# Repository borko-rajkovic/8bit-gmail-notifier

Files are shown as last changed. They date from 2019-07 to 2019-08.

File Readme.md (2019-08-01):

[][linkedin-url]

<!-- PROJECT LOGO -->
<br />
<p align="center">
  <a href="https://github.com/borko-rajkovic/8bit-gmail-notifier">
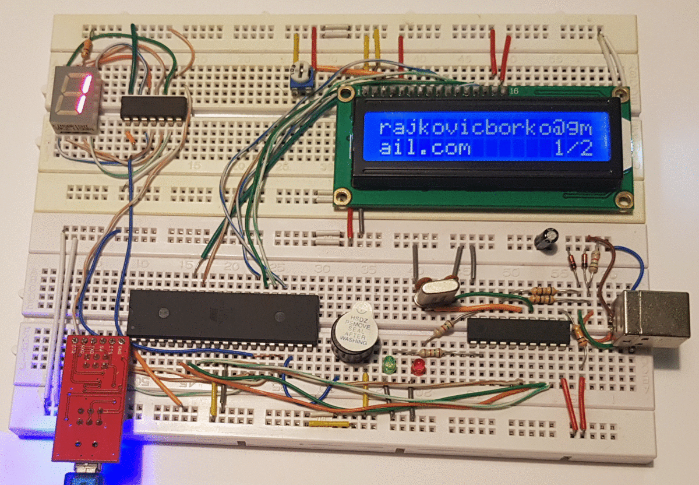
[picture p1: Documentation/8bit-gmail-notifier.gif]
    
  </a>

  <h3 align="center">8bit Gmail Notifier</h3>

  <p align="center">
    Breadboard Gmail notifier written in Assembly
    <br />
    <a href="https://github.com/borko-rajkovic/8bit-gmail-notifier/issues">Report Bug</a>
    ·
    <a href="https://github.com/borko-rajkovic/8bit-gmail-notifier/issues">Request Feature</a>
  </p>
</p>

<!-- TABLE OF CONTENTS -->

## Table of Contents

- [Demo](#demo)
- [Features](#features)
- [About the Project](#about-the-project)
  - [Built With](#built-with)
  - [Schematics](#schematics)
    - [Complete breadboard](#complete-breadboard)
    - [USBtinyISP Programmer](#usbtinyisp-programmer)
    - [BOM (Bill of materials)](#bom-bill-of-materials)
- [Getting Started](#getting-started)
  - [Pre-requisites](#pre-requisites)
  - [Set up project](#set-up-project)
  - [Connect to AVR](#connect-to-avr)
  - [Reading AVR memory and fuses](#reading-avr-memory-and-fuses)
  - [Writing fuses](#writing-fuses)
  - [Writing flash and EEPROM memory](#writing-flash-and-eeprom-memory)
- [Contributing](#contributing)
- [Contact](#contact)

<!-- DEMO -->

## Demo

Watch device in live action [here](https://youtu.be/EqjDfDrvmFI)

## Features

- Buzzer play melody on new mail
- 7-segment display of unread email count (animated)
- LCD display newest email sender and subject
- EEPROM data storage in case of power loss

<!-- ABOUT THE PROJECT -->

## About The Project

You always wanted to learn microcontroller programming in Assembly building something useful?

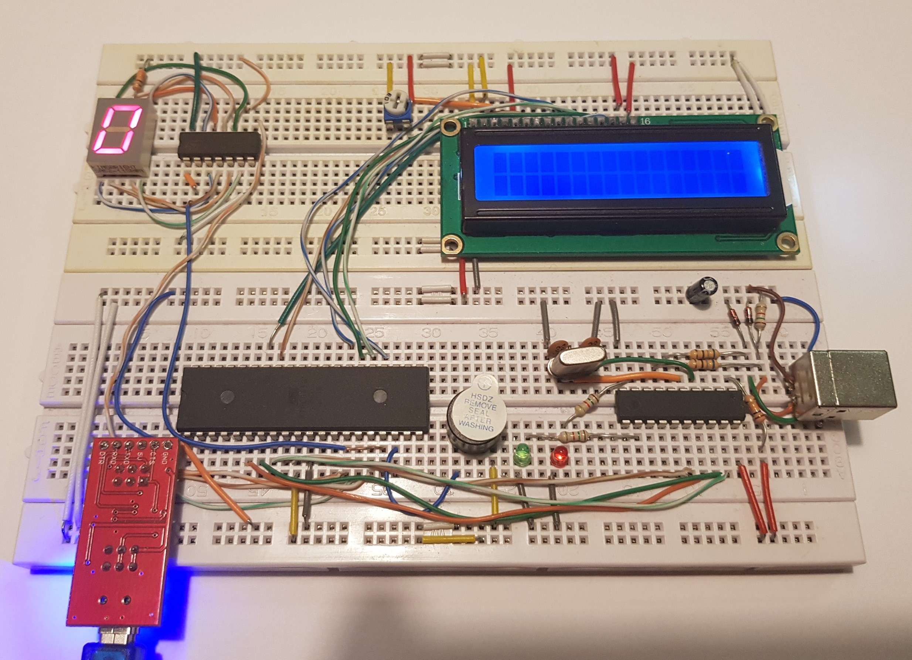
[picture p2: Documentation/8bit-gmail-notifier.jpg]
a


With this project you can learn the basic concepts of AVR MCU programming in Assembly, such as

- Using shift-register for 7-segment display
- Animating digit using Timer/Counter
- Writing to LCD display
- Making tones and melodies with PWM
- Read/Write to EEPROM
- Connecting to PC with UART

### Built With

Assembly - Atmel Studio 7.0

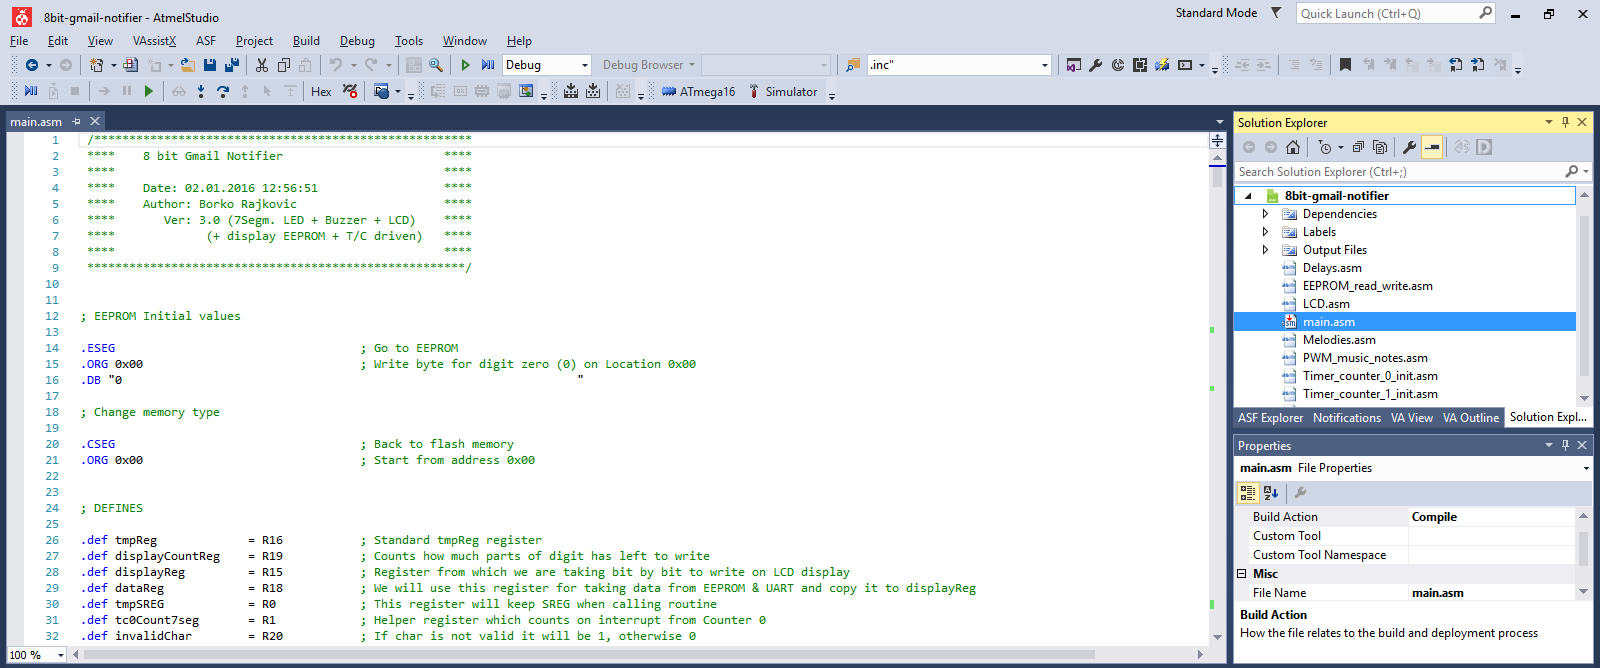
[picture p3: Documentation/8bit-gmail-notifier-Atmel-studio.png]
Atmel Studio


### Schematics

#### Complete breadboard

This breadboard includes home made USBtinyISP programmer. If you have your own, you can skip that part.

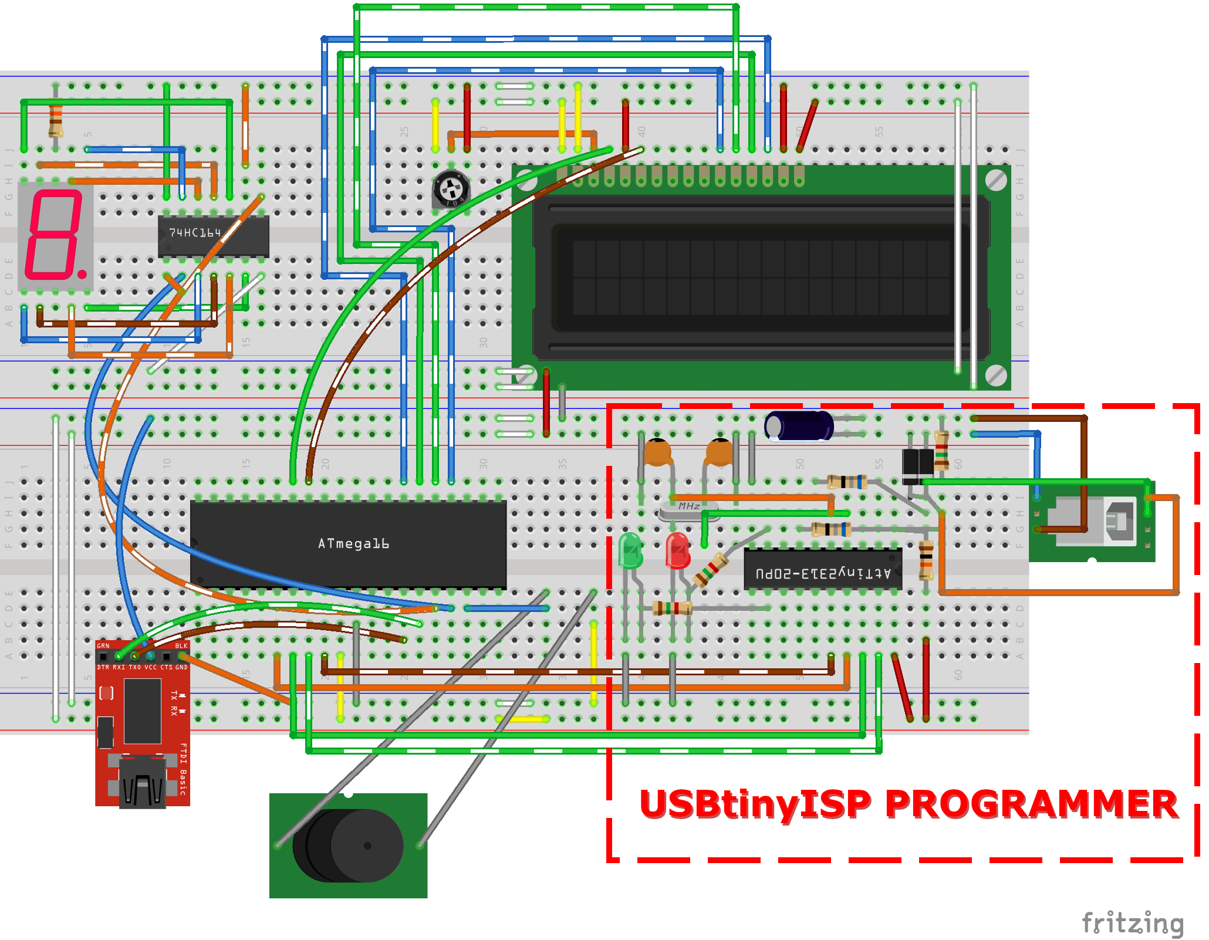
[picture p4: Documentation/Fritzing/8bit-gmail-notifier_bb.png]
8bit-gmail-notifier
[](https://github.com/borko-rajkovic/8bit-gmail-notifier)

#### USBtinyISP Programmer

As can be seen on breadboard diagram, USBtinyISP Programmer is surrounded by dashed red line. If you wish to build it yourself, here is the schema for it

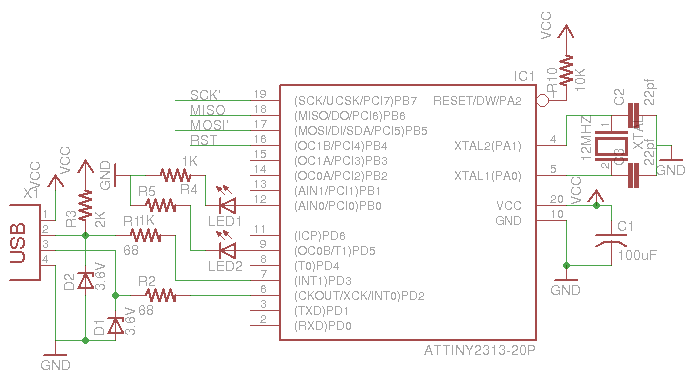
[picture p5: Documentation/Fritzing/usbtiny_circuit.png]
USBtinyISP


#### BOM (Bill of materials)

Following is the bill of materials needed for this project (not including parts for USBtinyISP programmer)

<table>
  <thead>
    <tr>
    <th>Amount</th>
    <th>Part Type</th>
    </tr>
  </thead>
  <tbody>
<tr>
    <td>2</td>
    <td>Breadboard</td>
</tr><tr>
    <td>1</td>
    <td>74HC164</td>
</tr><tr>
    <td>1</td>
    <td>7-Segment LED Display</td>
</tr><tr>
    <td>1</td>
    <td>ATmega16</td>
</tr><tr>
    <td>1</td>
    <td>FTDI Basic Programmer</td>
</tr><tr>
    <td>1</td>
    <td>Trimmer Potentiometer</td>
</tr><tr>
    <td>1</td>
    <td>330Ω Resistor</td>
</tr><tr>
    <td>1</td>
    <td>Buzzer 12mm</td>
</tr><tr>
    <td>1</td>
    <td>LCD-16X2</td>
</tr>
  </tbody>
</table>

Complete BOM list including parts for USBtinyISP programmer can be found [here](./Documentation/Fritzing/8bit-gmail-notifier-bom.html)

<!-- GETTING STARTED -->

## Getting Started

### Pre-requisites

- [Atmel Studio](https://www.microchip.com/mplab/avr-support/atmel-studio-7)
- [WinAVR](http://winavr.sourceforge.net/)
- [8bit-gmail-notifier-csharp-uart](https://github.com/borko-rajkovic/8bit-gmail-notifier-csharp-uart)

### Set up project

To get a local copy of the project up and running, simply

```sh
git clone https://github.com/borko-rajkovic/8bit-gmail-notifier
```

Atmel Studio project is in directory **8bit-gmail-notifier**

Once you open project, in Solution explorer (`Ctrl + Alt + L`) right click on project name, then on Properties and make sure all is selected as shown here

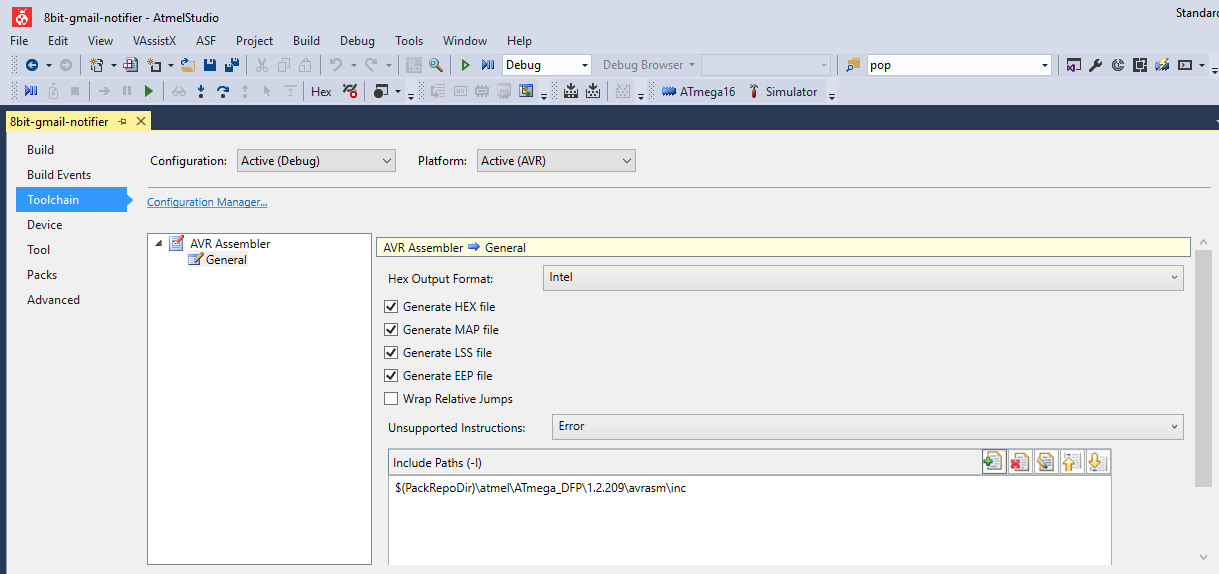
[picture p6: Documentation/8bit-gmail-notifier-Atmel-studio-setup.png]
Atmel-Studio-setup


### Connect to AVR

Make sure you installed WinAVR, connect USBtinyISP programmer to your PC and run

```
avrdude -c usbtiny -p m16
```

You should get something like this

```
avrdude: AVR device initialized and ready to accept instructions

Reading | ################################################## | 100% 0.02s

avrdude: Device signature = 0x1e9403

avrdude: safemode: Fuses OK

avrdude done.  Thank you.
```

### Reading AVR memory and fuses

To read memory and fuses from AVR simply run

```
avrdude -c usbtiny -p m16 -U flash:r:flash.hex:i -U lfuse:r:low_fuse_val.hex:i -U hfuse:r:high_fuse_val.hex:i
```

It will write flash memory to `flash.hex`, low fuse to `low_fuse_val` and high fuse to `high_fuse_val.hex`

Output should look like this

```
avrdude: AVR device initialized and ready to accept instructions

Reading | ################################################## | 100% 0.02s

avrdude: Device signature = 0x1e9403
avrdude: reading flash memory:

Reading | ################################################## | 100% 16.81s

avrdude: writing output file "flash.hex"
avrdude: reading lfuse memory:

Reading | ################################################## | 100% 0.01s

avrdude: writing output file "low_fuse_val.hex"
avrdude: reading hfuse memory:

Reading | ################################################## | 100% 0.01s

avrdude: writing output file "high_fuse_val.hex"

avrdude: safemode: Fuses OK

avrdude done.  Thank you.

```

### Writing fuses

You should set up fuses for your chip in following way

- hifh fuse values from [this](./Documentation/Atmega16_fuses/high_fuse_val.hex) file
- low fuse values from [this](./Documentation/Atmega16_fuses/low_fuse_val.hex) file

Command to set fuses is

```
avrdude -c usbtiny -p m16 -U lfuse:w:low_fuse_val.hex:i -U hfuse:w:high_fuse_val.hex:i
```

Output should be similar to writing flash or EEPROM memory, check bellow

### Writing flash and EEPROM memory

Once you run build, in Debug folder there will be two files

- `8bit-gmail-notifier.hex` - flash memory
- `8bit-gmail-notifier.eep` - EEPROM memory

In order to write to flash memory you should run

```
avrdude -c usbtiny -p m16 -U flash:w:8bit-gmail-notifier.hex:i
```

Output should look something like this

```
avrdude: AVR device initialized and ready to accept instructions

Reading | ################################################## | 100% 0.02s

avrdude: Device signature = 0x1e9403
avrdude: NOTE: FLASH memory has been specified, an erase cycle will be performed
         To disable this feature, specify the -D option.
avrdude: erasing chip
avrdude: reading input file "8bit-gmail-notifier.hex"
avrdude: writing flash (1560 bytes):

Writing | ################################################## | 100% 2.56s

avrdude: 1560 bytes of flash written
avrdude: verifying flash memory against 8bit-gmail-notifier.hex:
avrdude: load data flash data from input file 8bit-gmail-notifier.hex:
avrdude: input file 8bit-gmail-notifier.hex contains 1560 bytes
avrdude: reading on-chip flash data:

Reading | ################################################## | 100% 1.64s

avrdude: verifying ...
avrdude: 1560 bytes of flash verified

avrdude: safemode: Fuses OK

avrdude done.  Thank you.

```

Similar to this, writing to EEPROM should be done with this command

```
avrdude -c usbtiny -p m16 -U eeprom:w:8bit-gmail-notifier.eep:i
```

<!-- CONTRIBUTING -->

## Contributing

Contributions are what make the open source community such an amazing place to learn, inspire, and create. Any contributions you make are **greatly appreciated**.

1. Fork the Project
2. Create your Feature Branch (`git checkout -b feature/AmazingFeature`)
3. Commit your Changes (`git commit -m 'Add some AmazingFeature`)
4. Push to the Branch (`git push origin feature/AmazingFeature`)
5. Open a Pull Request

<!-- CONTACT -->

## Contact

Borko Rajkovic - [LinkedIn](https://linkedin.com/in/borko-rajkovic) - rajkovicborko@gmail.com

<!-- MARKDOWN LINKS & IMAGES -->

[linkedin-shield]: https://img.shields.io/badge/-LinkedIn-black.svg?style=flat-square&logo=linkedin&colorB=555
[linkedin-url]: https://linkedin.com/in/borko-rajkovic/
[product-screenshot]: ./Documentation/Fritzing/8bit-gmail-notifier_bb.png

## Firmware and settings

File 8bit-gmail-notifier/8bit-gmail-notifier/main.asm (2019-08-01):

 /******************************************************
 ****    8 bit Gmail Notifier                       ****
 ****                                               ****
 ****    Date: 02.01.2016 12:56:51                  ****
 ****    Author: Borko Rajkovic                     ****
 ****        Ver: 3.0 (7Segm. LED + Buzzer + LCD)   ****
 ****             (+ display EEPROM + T/C driven)   ****
 ****                                               ****
 ******************************************************/

 
; EEPROM Initial values

.ESEG                                    ; Go to EEPROM
.ORG 0x00                                ; Write byte for digit zero (0) on Location 0x00

.DB "0                                                                 "

; Change memory type

.CSEG                                    ; Back to flash memory
.ORG 0x00                                ; Start from address 0x00


; DEFINES

.def tmpReg             = R16            ; Standard tmpReg register
.def displayCountReg    = R19            ; Counts how much parts of digit has left to write
.def displayReg         = R15            ; Register from which we are taking bit by bit to write on LCD display
.def dataReg            = R18            ; We will use this register for taking data from EEPROM & UART and copy it to displayReg
.def tmpSREG            = R0             ; This register will keep SREG when calling routine
.def tc0Count7seg       = R1             ; Helper register which counts on interrupt from Counter 0
.def invalidChar        = R20            ; If char is not valid it will be 1, otherwise 0
.def toneDuration       = R17
.def notEndOfMusic      = R2
.def volume             = R3
.def biggerDigit        = R4
.def LCDPauseCountH     = R6
.def LCDPauseCountL     = R5
.def LCDCurrentChar     = R7
.def USARTinProgress    = r8
.def sameDigitReg       = r9
.def current7seg        = r10

.equ pauseLCD = 6

; INTERRUPTS

jmp Start                                ; Reset interrupt
nop nop                                  ; Since interrupt is addressed with 2 bytes, we should write 2 nop bytes for interrupt we do not use
nop nop
nop nop
nop nop
nop nop
nop nop                                    
nop nop                                    
nop nop
nop nop
nop nop
jmp USART_RX_COMPLETE                    ; USART Recieve completed interrupt; We cannot use pins PD0 and PD1 as GPIO because they are used for USART
nop nop
nop nop
nop nop
nop nop
nop nop
nop nop
nop nop
jmp TIMER0_COMP_INT                      ; Timer/Counter0 Compare Match (pin PB3 is used for this)
nop nop

; START

Start:
                                         ; Setup stack pointer for method calls (so "ret" could work)
    ldi     tmpReg, low(RAMEND)
    out     SPL, tmpReg
    ldi     tmpReg, high(RAMEND)
    out     SPH, tmpReg

                                         ; After restart initialization and reading from EEPROM, then display on LCD screen
    call    PORT_INIT
    call    TC0_INIT
    call    TC1_INIT
    call    USART_Init
    call    lcd_init_4d

    call    Refresh_data


; MAIN

main:
                                         ; Main function is empty, we are using interrupts exclusively
    jmp     main



; ---------------------------------------------------------------------------
; Name:     Refresh_data
; Purpose:  Display new data from EEPROM. If number of emails is bigger then before, play music
; Entry:    sameDigitReg, biggerDigit
; Exit:     no parameters
; Notes:    If number of emails is same, exit routine
;           otherwise continue to Loading_characters

Refresh_data:

    ; If same digit, then jump to end_LCD_display, otherwise go to continue_first_digit

    push    tmpReg
    mov     tmpReg, sameDigitReg
    cpi     tmpReg, 0x01
    pop     tmpReg
    brne    continue_first_digit

    rjmp    end_LCD_display

    ; If digit is bigger than before, play music, otherwise just refresh LCD display

    continue_first_digit:

    mov     tmpReg, biggerDigit
    cpi     tmpReg, 0x01
    brne    skip_reset_music
    call    Reset_music

    skip_reset_music:

    ; Set current char of LCD to 0, read from EEPROM to dataReg, format digit and display it

    ldi     tmpReg, 0x00
    mov     LCDCurrentChar, tmpReg
    call    EEPROM_read
    mov     current7seg, dataReg
    call    Format_digit
    call    Display_write_start

; ---------------------------------------------------------------------------
; Name:     Loading_characters
; Purpose:  Display new data from EEPROM
; Entry:    LCDCurrentChar
; Exit:     no parameters
; Notes:    Refresh_data does not have ret, so it will go through Loading_characters
;           this routine will be called from TIMER0_COMP_INT
;           Data is containing two sets of 32 characters delimited by pipe "|"
;                so in first set there will be 16 characters on first line and 16 on second line, which starts from position 17
;                for the second set, there are 32 characters prior to that set + delimiter (33) + 16 characters for first line (49)
;                so second line of second set starts at position 50

Loading_characters:

    ; Check if USART is in progress and if it's not, go to continue_loading_characters

    push    tmpReg
    mov     tmpReg, USARTinProgress
    cpi     tmpReg, 0x01
    pop     tmpReg
    brne    continue_loading_characters
    ret

    continue_loading_characters:

    ; increment LCDCurrentChar

    mov     tmpReg, LCDCurrentChar
    inc     tmpReg
    mov     LCDCurrentChar, tmpReg

    ; check if first data set reached the end

    cpi     tmpReg, 33
    breq    finished_loading_characters

    ; check if second data set reached the end

    cpi     tmpReg, 65
    breq    finished_loading_characters

    call EEPROM_read

    ; set cursor to second line in case current position is 17 or 50

    cpi     tmpReg, 17
    breq    second_line_set_cursor
    cpi     tmpReg, 50
    breq    second_line_set_cursor

    ; if not characters that starts second line, skip setting cursor to second line

    rjmp    skip_second_line_set_cursor

    second_line_set_cursor:

    push    tmpReg

    ; setting cursor to point to second line

    ldi     tmpReg, lcd_LineTwo          ; set up the initial DDRAM address
    ori     tmpReg, lcd_SetCursor        ; convert the plain address to a set cursor instruction
    call    lcd_write_instruction_4d     ; set up the first DDRAM address
    ldi     tmpReg, 80                   ; 40 uS delay (min)
    call    delayTx1uS

    pop     tmpReg

    skip_second_line_set_cursor:

    ; if position of char in data is 1 (first character of first set)
    ; or 34 (first character of second set), we need to set cursor to first line

    cpi     tmpReg, 34
    breq    first_line_set_cursor
    cpi     tmpReg, 1
    breq    first_line_set_cursor

    ; skip setting cursor to first line if not expected
    rjmp    skip_first_line_set_cursor

    first_line_set_cursor:

    ; set cursor to first line

    push    tmpReg

    ldi     tmpReg, lcd_LineOne          ; set up the initial DDRAM address
    ori     tmpReg, lcd_SetCursor        ; convert the plain address to a set cursor instruction
    call    lcd_write_instruction_4d     ; set up the first DDRAM address
    ldi     tmpReg, 80                   ; 40 uS delay (min)
    call    delayTx1uS

    pop     tmpReg

    skip_first_line_set_cursor:

    ; write data from dataReg to LCD

    call    lcd_write_character_4d_dataReg

    push    tmpReg
    ldi     tmpReg, 80                   ; 40 uS delay (min)
    call    delayTx1uS
    pop     tmpReg

    ; continue writing to LCD until finished_loading_characters is called

    rjmp    Loading_characters

    finished_loading_characters:

    ; check if current position is 65 (end of second set)
    ; if so, reset position to 0

    cpi     tmpReg, 65
    brne    end_LCD_display

    ldi     tmpReg, 0

    end_LCD_display:

ret

; PORT_INIT

PORT_INIT:

    ldi     tmpReg, 0b00011100           ; tmpReg - set DDRD (exit ports) and PORTD (values on ports)
    out     DDRD, tmpReg                 ; (since it's port D we avoid TxD, RxD) PIND2=CLK; PIND3=Data; OC1B=Buzzer
    ldi     tmpReg, 0b00001100                
    out     PORTD, tmpReg

    ret


.include    "Timer_counter_1_init.asm"
.include    "Timer_counter_0_init.asm"
.include    "EEPROM_read_write.asm"

; Timer/Counter0 Interrupt Service Routine

TIMER0_COMP_INT:

    ; this interrupt will trigger on 1ms

    push    tmpReg

    ; adding one to LCDPauseCountL and LCDPauseCountH (add 0 to LCDPauseCountH with carry from adding 1 to LCDPauseCountL)

    ldi     tmpReg, 0x01
    add     LCDPauseCountL, tmpReg
    ldi     tmpReg, 0x00
    adc     LCDPauseCountH, tmpReg

    ; we are counting up to pauseLCD seconds
    ; (actually, it will not be exact, for example 6 << 10 = 6144 ms)

    ; if high and low part of our count is not same as desired, go to LCDisPause

    mov     tmpReg, LCDPauseCountH
    cpi     tmpReg, HIGH(pauseLCD << 10)
    brne    LCDisPause
    mov     tmpReg, LCDPauseCountL
    cpi     tmpReg, LOW(pauseLCD << 10)
    brne    LCDisPause

    ; otherwise, reset our pause counter to zero and call Loading_characters to show other set on display
    ; (if first set was shown, show second and vice-verse)

    ldi     tmpReg, 0x00
    mov     LCDPauseCountH, tmpReg
    mov     LCDPauseCountL, tmpReg

    pop     tmpReg

    call    Loading_characters

    push    tmpReg

    LCDisPause:

    pop     tmpReg

    ; In all cases, call Play_music to check if tone or volume needs to be changed

    call    Play_music

    ; Animate number of emails on 7-segment display
    ;
    ; Use tc0Count7seg to count to 100ms
    ; Once it reach 100ms:
    ;    - clear tc0Count7seg
    ;    - check if there are still bits to move to shift register,
    ;        if there are none, then exit;
    ;        otherwise go to Display_write_continue

    push    tmpReg

    INC     tc0Count7seg                 ; Increment tc0Count7seg by one
    mov     tmpReg, tc0Count7seg         ; Copy tc0Count7seg to tmpReg
    cpi     tmpReg, 100                  ; Compare tc0Count7seg with 100 (for 100ms, actually it will be more)
    pop     tmpReg                       ; IMPORTANT! If we do not pop here,
                                         ; then in a stack it will be tmpReg and ret will return to address to which points tmpReg,
                                         ; instead of the one that is written in a moment we entered routine

    BRNE    TIMER0_COMP_INT_EXIT         ; If tc0Count7seg != 100 then exit; otherwise continue

    clr     tc0Count7seg                 ; Clear tc0Count7seg, so it can count from start

    cpi     displayCountReg, 0           ; Compare displayCountReg to 0
    BRNE    Display_write_continue       ; If displayCountReg != 0 then go to routine, otherwise exit

    TIMER0_COMP_INT_EXIT:
    reti                                 ; reti will finish interrupt and set global interrupt to 1

; Start animation of number of emails on 7-segment display using shift register and shifting each bit every 100ms

Display_write_start:

    mov     displayReg, dataReg          ; Copy from dataReg to displayReg
    ldi     displayCountReg, 8           ; 8 bits are used, so we will count with displayCountReg from 8 to 0

Display_write_continue:

    push    tmpReg

    mov     tmpReg, displayReg           ; Copy displayReg to tmpReg
    andi    tmpReg, 1                    ; Take just first bit
    lsl     tmpReg                       ; Move tmpReg 3 places left
    lsl     tmpReg
    lsl     tmpReg

    out     PORTD, tmpReg                ; Set value of tmpReg to PORTD; PIND3 is set to data (for shift register) and PIND2 is set to 0 now
    sbi     PORTD, PIND2                 ; Set PIND2 (Clock for shift register)
    cbi     PORTD, PIND2                 ; Clear PIND2 and with that one puls is finished => 0 - 1 - 0

    pop     tmpReg

    lsr     displayReg                   ; Shift right, move on to next bit
    subi    displayCountReg, 1           ; Decrement displayCountReg by 1
    reti


.include    "USART_init_transmit.asm"


; USART Rx Complete Interrupt

USART_RX_COMPLETE:

    in      dataReg, UCSRA               ; First, we need to read content of UCSRA (USART Control and Status Register A),
                                         ;     because due to reading of UDR (USART Data Register) data are deleted from UCSRA
                                         ; UCSRA contains control bits for Frame Error (FE), Data Over-Run (DOR) and Parity Error (PE)
                                         ; After getting content of UCSRA we do logical AND with desired control bits

    andi    dataReg, (1<<FE)|(1<<DOR)|(1<<PE)

    push    tmpReg
    ldi     tmpReg, $1                   ; We will compare control bits with 1 (comparison is >= type)
    cp      dataReg, tmpReg
    pop     tmpReg
    
    BRGE    RX_interrupt_exception       ; If any bit returned error, dataReg will be > 1 and it will go to RX_interrupt_exception

    rjmp    skip_RX_interrupt_exception
    
    RX_interrupt_exception:

    in      dataReg, UDR                 ; Put content of UDR (USART Data Register) to dataReg
                                         ; Cleanup of UCSRA is required, otherwise next frame could not be received
    reti

    skip_RX_interrupt_exception:

    in      dataReg, UDR                 ; Put content of UDR (USART Data Register) to dataReg
    call    USART_Transmit               ; After receiving, we are transmiting back message via UART for confirmation

    cli                                  ; disable global interrupt



    ; At this point we have our data from UART in dataReg
    ;
    ; We are expecting following data to be received via UART:
    ;
    ; 1) start of transmit               ; value is 0x02
    ; 2) number of emails                ; single digit from 0 to 9, or dot "." if more than 9 new messages
    ; 3) 32 chars for first data set     ; LCD contains 2 lines X 16 chars, so first data set is 32 chars long
    ; 4) delimiter (pipe "|")            ; this is used to separate two data sets
    ; 5) 32 chars for second data set    ; second data set, also 32 chars long
    ; 6) end of transmit and Refresh     ; value is 0x03



    ; Case 1)
    ;
    ; Compare if dataReg is 0x02; if not, skip this code
    ; otherwise, set USARTinProgress to 1 and set LCDCurrentChar to 0

    cpi     dataReg, 0x02
    brne    not_start_of_transmit
    push    tmpReg
    ldi     tmpReg, 0x01
    mov     USARTinProgress, tmpReg
    ldi     tmpReg, 0x00
    mov     LCDCurrentChar, tmpReg
    pop     tmpReg
    reti

    not_start_of_transmit:

    ; Case 6)
    ;
    ; Compare if dataReg is 0x03; if not, skip this code
    ; otherwise, set USARTinProgress to 0 and call Refresh_data

    cpi     dataReg, 0x03
    brne    not_end_of_transmit
    push    tmpReg
    ldi     tmpReg, 0x00
    mov     USARTinProgress, tmpReg
    pop     tmpReg
    call    Refresh_data
    reti
    
    not_end_of_transmit:

    ; Check if USARTinProgress
    ; if not, skip to end

    push    tmpReg
    mov     tmpReg, USARTinProgress
    cpi     tmpReg, 0x01
    pop     tmpReg
    brne    not_USARTinProgress

    ; Here we know that we want to process data from UART
    ;
    ; We will write dataReg to EEPROM and increment LCDCurrentChar

    push    tmpReg
    mov     tmpReg, LCDCurrentChar
    call    EEPROM_write                 ; Write dataReg to EEPROM on address given in tmpReg
    inc     LCDCurrentChar               ; increment LCDCurrentChar
    pop     tmpReg

    ; Case 2)
    ;
    ; First we will check if it's case two by checking is LCDCurrentChar == 1

    push    tmpReg
    mov     tmpReg, LCDCurrentChar
    cpi     tmpReg, 0x01
    pop     tmpReg
    brne    not_case_2                   ; Skip Case 2) if LCDCurrentChar != 1

    ; Compare new number of emails with previous

    push    tmpReg
    ldi     tmpReg, 0x00
    mov     sameDigitReg, tmpReg         ; Reset sameDigitReg to 0
    pop     tmpReg

    cp      dataReg, current7seg         ; Compare old number of emails (current7seg register) with new one (dataReg)
    brne    number_of_emails_changed     ; If they are same, we are marking sameDigitReg to 1 and finish this routine for case 2)

    number_of_emails_not_changed:

    push    tmpReg
    ldi     tmpReg, 0x01
    mov     sameDigitReg, tmpReg         ; Set sameDigitReg to 1 to indicate that new and previous number of emails are same
    pop     tmpReg

    rjmp    number_of_emails_same


    number_of_emails_changed:

    ; Reset bigger digit to 0

    push    tmpReg
    ldi     tmpReg, 0x00
    mov     biggerDigit, tmpReg          ; Reset biggerDigit to 0
    pop     tmpReg

    ; if old number of emails was "." then new number cannot be bigger

    push    tmpReg
    mov     tmpReg, current7seg
    cpi     tmpReg, '.'
    pop     tmpReg
    breq    USART_digit_not_bigger

    ; compare old number of emails with new one if old one was != "."

    cp      current7seg, dataReg         ; compare dataReg (new emails count) and current7seg (old emails count)
    brlo    email_count_got_bigger       ; if current7seg is lower than dataReg, go to email_count_got_bigger
    cpi     dataReg, 0x2E                ; compare dataReg with "."
    breq    email_count_got_bigger       ; if dataReg == ".", then go to email_count_got_bigger
    rjmp    USART_digit_not_bigger       ; at this point, we know that new email count is lower than old count
    
    email_count_got_bigger:

    push    tmpReg
    ldi     tmpReg, 0x01
    mov     biggerDigit, tmpReg          ; Set biggerDigit to 1 to indicate that new email count is bigger than old one, so we can play music
    pop     tmpReg

    USART_digit_not_bigger:

    ; Cases 3), 4), 5)
    not_case_2:

    cli                                  ; Global interrupt disable

    not_USARTinProgress:
    number_of_emails_same:

    in      dataReg, UDR                 ; Put content of UDR (USART Data Register) to dataReg
                                         ; Cleanup of UCSRA is required, otherwise next frame could not be received

    sei                                  ; Global interrupt enable
    ret


; Format digit

Format_digit:

digit_0:
    cpi     dataReg, 0x30                ; With cpi we are comparing char and ASCII 0 (0x30)
    brne    digit_1                      ; If not equal, move on to next digit
    ldi     dataReg, 0b00011000          ; If equal, format it for display
    ret

digit_1:
    cpi     dataReg, 0x31
    brne    digit_2
    ldi     dataReg, 0b11011110                
    ret

digit_2:
    cpi     dataReg, 0x32
    brne    digit_3
    ldi     dataReg, 0b00110100                
    ret

digit_3:
    cpi     dataReg, 0x33
    brne    digit_4
    ldi     dataReg, 0b10010100                
    ret

digit_4:
    cpi     dataReg, 0x34
    brne    digit_5
    ldi     dataReg, 0b11010010                
    ret

digit_5:
    cpi     dataReg, 0x35
    brne    digit_6
    ldi     dataReg, 0b10010001                
    ret

digit_6:
    cpi     dataReg, 0x36
    brne    digit_7
    ldi     dataReg, 0b00010001                
    ret

digit_7:
    cpi     dataReg, 0x37
    brne    digit_8
    ldi     dataReg, 0b11011100                
    ret

digit_8:
    cpi     dataReg, 0x38
    brne    digit_9
    ldi     dataReg, 0b00010000                
    ret

digit_9:
    cpi     dataReg, 0x39
    brne    digit_9_dot
    ldi     dataReg, 0b10010000                
    ret

digit_9_dot:
    ldi     dataReg, 0b10000000          ; Represents "9." if more than 9
    ret


; ---------------------------------------------------------------------------
; Name:     Reset_music
; Purpose:  Reseting melody to start
; Entry:    no parameters
; Exit:     no parameters
; Notes:    Z register is set to point to address in memory where our melody is written
;           We reset toneDuration and notEndOfMusic registers to 1
;           After that, we are reading 4 times from memory because melodies are written in pairs,
;               out of which first pair is a volume (example: .DW 40, 0)
;               and other pairs are tone and duration of that particular note (example: .DW E7, 84)
;               as .DW is writing word, it means each part of pair is 2 bytes long, hence 4 bytes are filling out space of two pairs;
;               reading is done first by reading low, then high part of 16 bits

Reset_music:

    push    tmpReg

    ldi     ZH, HIGH(super_mario << 1)   ; you can choose between super_mario and start_wars melodies
    ldi     ZL, LOW(super_mario << 1)    ; or you can create your own melody in Melodies.inc
    ; ldi   ZH, HIGH(starwars << 1)
    ; ldi   ZL, LOW(starwars << 1)
    ldi     toneDuration, 0x01           ; set toneDuration and notEndOfMusic to 1
    ldi     tmpReg, 0x01
    mov     notEndOfMusic, tmpReg

    lpm     tmpReg, Z+                   ; set up volume register
    mov     volume, tmpReg
    lpm     tmpReg, Z+ 
    lpm     tmpReg, Z+ 
    lpm     tmpReg, Z+ 

    pop     tmpReg

    ret
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

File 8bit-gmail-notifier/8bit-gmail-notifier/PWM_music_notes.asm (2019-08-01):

/*
 * PWM_music_notes.inc
 *
 *        Date: 09.01.2016 15:58:11
 *        Author: Borko Rajkovic
 * 
 *        Input Capture Register (ICR) values for AVR MCU to create sounds with PWM
 *        
 *        Clock:          8000000 [Hz]
 *        Prescaler:      8
 *        PWM mode:       phase/frequency correct 16 bit
 *        
 *        freq = fclk/(2*N*TOP) ; N-prescaler; TOP = ICR
 *        ICR = fclk/(2*N*freq) ; freq - desired frequency
 *
 *        Example - tone F2 (frequency is 87,31Hz):
 *
 *           ICR = 8MHz(2*8*87,31)=5726,72 ~ 5727
 *
 *           freq = 8MHz(2*8*5727)=87,3057 Hz ~ 87,31 Hz
 *
 *           Error = (87,3057/87,31 - 1)*100 = 0,004%
 * 
 */ 

.nolist

#ifndef __PWM_NOTES_H__
#define __PWM_NOTES_H__

/* Pause */
.equ P = 1

/* end */
.equ MUSIC_END  = 0

/* Octave #2 */

.equ A2         =    4545             /* PWM: 110.01 Hz, note freq:   110.00 Hz, error 0.01% */
.equ A2b        =    4816             /* PWM: 103.82 Hz, note freq:   103.83 Hz, error 0.01% */
.equ a2x        =    4290             /* PWM: 116.55 Hz, note freq:   116.54 Hz, error 0.01% */
.equ ais2       =    4290             /* PWM: 116.55 Hz, note freq:   116.54 Hz, error 0.01% */
.equ b2         =    4050             /* PWM: 123.46 Hz, note freq:   123.47 Hz, error 0.01% */
.equ b2b        =    4290             /* PWM: 116.55 Hz, note freq:   116.54 Hz, error 0.01% */
.equ c2         =    7645             /* PWM:  65.40 Hz, note freq:    65.41 Hz, error 0.01% */
.equ c2x        =    7215             /* PWM:  69.30 Hz, note freq:    69.30 Hz, error 0.01% */
.equ cis2       =    7215             /* PWM:  69.30 Hz, note freq:    69.30 Hz, error 0.01% */
.equ d2         =    6810             /* PWM:  73.42 Hz, note freq:    73.42 Hz, error 0.01% */
.equ d2b        =    7215             /* PWM:  69.30 Hz, note freq:    69.30 Hz, error 0.01% */
.equ d2x        =    6428             /* PWM:  77.78 Hz, note freq:    77.78 Hz, error 0.00% */
.equ dis2       =    6428             /* PWM:  77.78 Hz, note freq:    77.78 Hz, error 0.00% */
.equ E2         =    6067             /* PWM:  82.41 Hz, note freq:    82.41 Hz, error 0.01% */
.equ E2b        =    6428             /* PWM:  77.78 Hz, note freq:    77.78 Hz, error 0.00% */
.equ F2         =    5727             /* PWM:  87.31 Hz, note freq:    87.31 Hz, error 0.00% */
.equ F2x        =    5405             /* PWM:  92.51 Hz, note freq:    92.50 Hz, error 0.01% */
.equ Fis2       =    5405             /* PWM:  92.51 Hz, note freq:    92.50 Hz, error 0.01% */
.equ G2         =    5102             /* PWM:  98.00 Hz, note freq:    98.00 Hz, error 0.00% */
.equ G2b        =    5405             /* PWM:  92.51 Hz, note freq:    92.50 Hz, error 0.01% */
.equ G2x        =    4816             /* PWM: 103.82 Hz, note freq:   103.83 Hz, error 0.01% */
.equ Gis2       =    4816             /* PWM: 103.82 Hz, note freq:   103.83 Hz, error 0.01% */
.equ H2         =    4050             /* PWM: 123.46 Hz, note freq:   123.47 Hz, error 0.01% */
.equ H2b        =    4290             /* PWM: 116.55 Hz, note freq:   116.54 Hz, error 0.01% */
.equ bH2        =    4290             /* PWM: 116.55 Hz, note freq:   116.54 Hz, error 0.01% */
.equ xA2        =    4290             /* PWM: 116.55 Hz, note freq:   116.54 Hz, error 0.01% */
.equ xC2        =    7215             /* PWM:  69.30 Hz, note freq:    69.30 Hz, error 0.01% */
.equ xF2        =    5405             /* PWM:  92.51 Hz, note freq:    92.50 Hz, error 0.01% */
.equ xG2        =    5102             /* PWM:  98.00 Hz, note freq:    98.00 Hz, error 0.00% */
                                                                       
/* Octave #3 */                                                           
                                                                       
.equ A3         =    2273             /* PWM: 219.97 Hz, note freq:   220.00 Hz, error 0.01% */
.equ A3b        =    2408             /* PWM: 207.64 Hz, note freq:   207.65 Hz, error 0.01% */
.equ A3x        =    2145             /* PWM: 233.10 Hz, note freq:   233.08 Hz, error 0.01% */
.equ Ais3       =    2145             /* PWM: 233.10 Hz, note freq:   233.08 Hz, error 0.01% */
.equ B3         =    2025             /* PWM: 246.91 Hz, note freq:   246.94 Hz, error 0.01% */
.equ B3b        =    2145             /* PWM: 233.10 Hz, note freq:   233.08 Hz, error 0.01% */
.equ C3         =    3822             /* PWM: 130.82 Hz, note freq:   130.81 Hz, error 0.01% */
.equ C3x        =    3608             /* PWM: 138.58 Hz, note freq:   138.59 Hz, error 0.01% */
.equ Cis3       =    3608             /* PWM: 138.58 Hz, note freq:   138.59 Hz, error 0.01% */
.equ D3         =    3405             /* PWM: 146.84 Hz, note freq:   146.83 Hz, error 0.01% */
.equ D3b        =    3608             /* PWM: 138.58 Hz, note freq:   138.59 Hz, error 0.01% */
.equ D3x        =    3214             /* PWM: 155.57 Hz, note freq:   155.56 Hz, error 0.00% */
.equ Dis3       =    3214             /* PWM: 155.57 Hz, note freq:   155.56 Hz, error 0.00% */
.equ E3         =    3034             /* PWM: 164.80 Hz, note freq:   164.81 Hz, error 0.01% */
.equ E3b        =    3214             /* PWM: 155.57 Hz, note freq:   155.56 Hz, error 0.00% */
.equ F3         =    2863             /* PWM: 174.64 Hz, note freq:   174.61 Hz, error 0.02% */
.equ F3x        =    2703             /* PWM: 184.98 Hz, note freq:   185.00 Hz, error 0.01% */
.equ Fis3       =    2703             /* PWM: 184.98 Hz, note freq:   185.00 Hz, error 0.01% */
.equ G3         =    2551             /* PWM: 196.00 Hz, note freq:   196.00 Hz, error 0.00% */
.equ G3b        =    2703             /* PWM: 184.98 Hz, note freq:   185.00 Hz, error 0.01% */
.equ G3x        =    2408             /* PWM: 207.64 Hz, note freq:   207.65 Hz, error 0.01% */
.equ Gis3       =    2408             /* PWM: 207.64 Hz, note freq:   207.65 Hz, error 0.01% */
.equ H3         =    2025             /* PWM: 246.91 Hz, note freq:   246.94 Hz, error 0.01% */
.equ H3b        =    2145             /* PWM: 233.10 Hz, note freq:   233.08 Hz, error 0.01% */
.equ bH3        =    2145             /* PWM: 233.10 Hz, note freq:   233.08 Hz, error 0.01% */
.equ xA3        =    2145             /* PWM: 233.10 Hz, note freq:   233.08 Hz, error 0.01% */
.equ xC3        =    3608             /* PWM: 138.58 Hz, note freq:   138.59 Hz, error 0.01% */
.equ xF3        =    2703             /* PWM: 184.98 Hz, note freq:   185.00 Hz, error 0.01% */
.equ xG3        =    2551             /* PWM: 196.00 Hz, note freq:   196.00 Hz, error 0.00% */
                                                                       
/* Octave #4 */                                                           
                                                                       
.equ A4         =    1136             /* PWM: 440.14 Hz, note freq:   440.00 Hz, error 0.03% */
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
